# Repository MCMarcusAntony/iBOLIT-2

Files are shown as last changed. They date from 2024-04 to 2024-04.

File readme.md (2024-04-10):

--------------------------------------------------------------------------------
New iBolit Simple Diagnostics Cartridge version based on previous work done by
the RBSC group.
--------------------------------------------------------------------------------
- Last 16.07.2022 updates included.
- PCB design converted to KiCAD.
- All parts moved to throught hole to help to begginers build.
- Fuses for all voltages on the top slot.
- Connection to a right hand daughter board added.

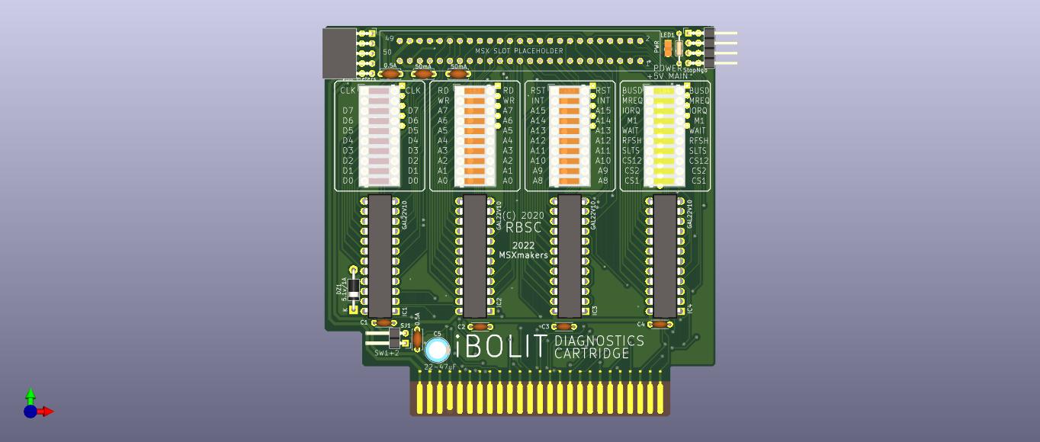
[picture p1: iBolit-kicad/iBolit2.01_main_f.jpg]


- Stop'n'go secondary daughter board design added.

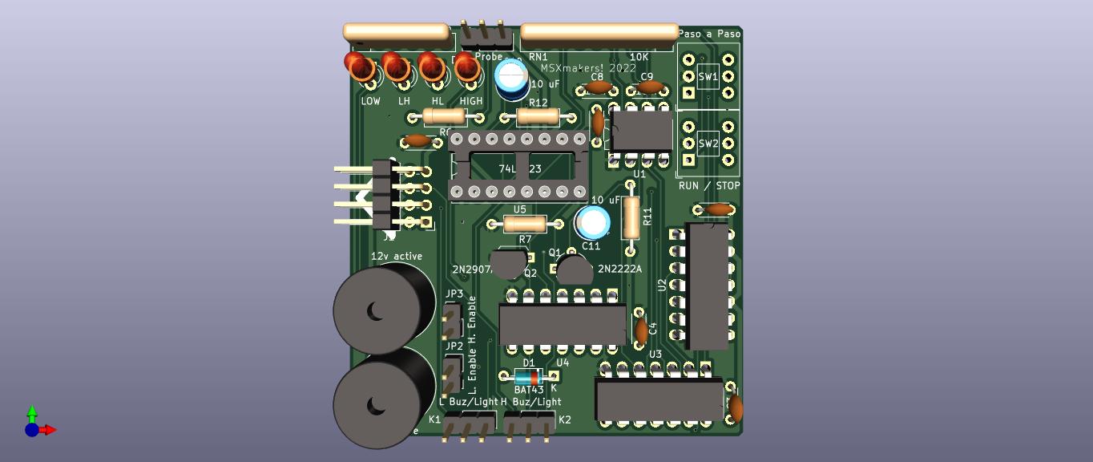
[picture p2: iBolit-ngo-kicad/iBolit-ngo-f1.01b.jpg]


Tools added to this board are:
- Logic probe included on Top three pin connector.
- Lighting and acoustic signals to identify HIGH and LOW status.

Code analisys tools (not properly working yet):
- Stop/Go switch the cpu to stop procesing opcodes.
- Step pushbutton to run just an opcode each time.

Development based on Steve Ciarcia design:
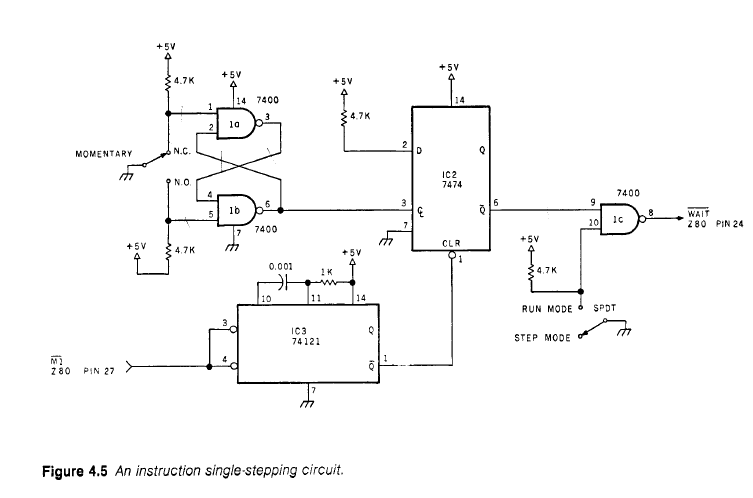
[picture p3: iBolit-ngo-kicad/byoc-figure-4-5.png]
byoc-figure-4-5


--------------------------------------------------------------------------------
iBolit Simple Diagnostics Cartridge
Copyright (c) 2020-2022 RBSC
Last updated: 16.07.2022
--------------------------------------------------------------------------------

UPDATE from 16.07.2022
----------------------

It's recommended to update the cartridge with an overvoltage protection. See the "iBolit_fuse.jpg" image in the Pics folder!

To install the overvoltage protection, isolate pin 24 of IC1 - cut the traces on both sides of the pin. Then purchase and
solder a 5.1V 1W rated zener diode between pins 12 and 24, the cathode should be connected to pin 24. Solder resettable fuse
0.5A between C2 and pin 24 of IC1. Solder a wire between C5 and the cut off trace to supply power to the voltmeters.

This way the PLD ICs and LEDs will be protected from the overvoltage while the 5V voltmeter will show exact voltage on the slot
connector.

About
-----

iBolit is a simple diagnostics cartridge. During the previous years we've seen numerous messages from MSX users, whose computers
suddenly stopped working after being removed from the storage or after another power cycle. Many people complained about black
screens or about total power failure. It's a known fact that RAM and other elements may go bad during storing or at power-on.
Diagnosing those problems usually starts from checking the power rails, clock signals, reset signal's state and activity on data
and address bus. It has been decided to create a simple diagnostics cartridge that could help to perform the initial check of a
computer and rule out the most common problems.

The cartridge that we named "iBolit" ( see Doctor Aybolit) was created using the GAL22V10 programmable logic chips, LED assemblies
and volt/ammeters from the PC's USB socket tester dongles. There's a cartridge slot installed on the top of iBolit cartridge's
board. There one can insert any cartridge including the one with MSX diagnostics ROM (there are a few, but it would be nice to
create a universal one). The GAL firmware is very primitive - if there's a high level on input, the LED connected to the output
will light up. The cartridge is fairly cheap to build - maximum 12-15 Euro - and is relatively easy to assemble. The daughterboard
with voltmeters is detachable.

Where to buy parts
------------------

The parts for assembling the cartridge can be purchased from these sellers on AliExpress:

 - https://www.aliexpress.com/item/32929139598.html   (buy the one with gray case and USB connectors on the left and right side)
 - https://www.aliexpress.com/item/4000078359420.html (buy 2 converters)
 - https://www.aliexpress.com/item/4001336380255.html (buy 2x5 pin headers)
 - https://www.aliexpress.com/item/32890057619.html   (buy 2x5 pin connectors)
 - https://www.aliexpress.com/item/4000970562846.html (also buy blue and yellow colors)
 - https://www.aliexpress.com/item/32800771545.html   (or use a different 5mm LED)
 - https://www.aliexpress.com/item/32918831775.html   (buy 1kOhm SMD resistor assemblies)
 - https://www.aliexpress.com/item/32948284513.html   (this LED is for the -12v voltmeter)
 - https://www.aliexpress.com/item/32375666910.html   (buy 10uF and 47uF capacitors)
 - https://www.aliexpress.com/item/4001146953252.html (buy 50-pin angled slot connector)

Assembling notes
----------------

Please read the following notes carefully:

 - It's highly recommended to install ceramic capacitors everywhere on the board. For the DC-DC converters the ceramic 10uF
   capacitors are a must

 - To adapt the voltmeters to work with iBolit, you need to first carefully open the USB tester's case with a knife and remove
   the board. Then desolder both indicator panels (mark one indicator panel to know where it came from) and desolder both USB
   connectors from the board. After that solder the indicator panels back to the board, but as low as possible. And finally
   solder two 4-pin pin headers to the board, the pins will have to be forces into the board because the distance between the
   holes is not 2.54mm

 - The voltmeter with a separate red LED is for -12v, it should be installed on the lowest position of the daughterboard. See
   the reference images

 - To install a small red LED to the -12v voltmeter (this step is optional), solder the cathode to the upper GND track and
   anode to the second pin from the top. See the reference images. The LED should be a bit above the voltmeter's board

 - Please note that LED assemblies may have incorrect key position! So please always test the LED assemblies with multimeter
   in the diode testing mode to find the correct polarity. The cathode should be on the right, like marked on the board

 - The pins of both DC-DC converters should be carefully bent at 90 degree angle and the converters have to be installed
   face-down. See the reference images

 - The GAL chips need to be programmed with the firmware before use. A widespread TL866 programmer will do just fine. Use
   the .JED firmware file from the "Firmware" folder and the "GAL22V10D" chip type when programming

 - Instead of one blue and two red LED assemblies you might want to install one red and two blue LED assemblies. Make your
   own choice. It's recommended to install the yellow LED assembly at the rightmost position. If you are installing the
   green LED assembly, you need to select a different value for the resistor assembly, for example 330 Ohm instead of 1kOhm

 - Before inserting the diagnostics board into the MSX slot it's highly recommend to make sure that +5v on the slot is within
   acceptable range (not more than 6-7v!), otherwise the diagnostics board may be damaged. The device doesn't have the
   over-voltage protection on the +5v rail

 - The daughterboard with voltmeters is detachable. When it is detached, no power will be supplied to the upper cartridge slot.
   If you need to use the cartridge slot without the attached daughterboard, you need to put 5 jumpers horizontally on 5 pairs
   of pins of the connector

IMPORTANT!
----------

The RBSC provides all the files and information for free, without any liability (see the disclaimer.txt file). The provided information,
software or hardware must not be used for commercial purposes unless permitted by the RBSC. Producing a small amount of bare boards for
personal projects and selling the rest of the batch is allowed without the permission of RBSC.

When the sources of the tools are used to create alternative projects, please always mention the original source and the copyright!

Contact information
-------------------

The members of RBSC group Tnt23, Wierzbowsky, Pencioner, Ptero, GreyWolf, SuperMax and DJS3000 can be contacted via the group's e-mail
address:

info@rbsc.su

The group's coordinator could be reached via this e-mail address:

admin@rbsc.su

The group's website can be found here:

https://rbsc.su/
https://rbsc.su/ru

The RBSC's hardware repository can be found here:

https://github.com/rbsc

The RBSC's 3D model repository can be found here:

https://www.thingiverse.com/groups/rbsc/things

-= ! MSX FOREVER ! =-

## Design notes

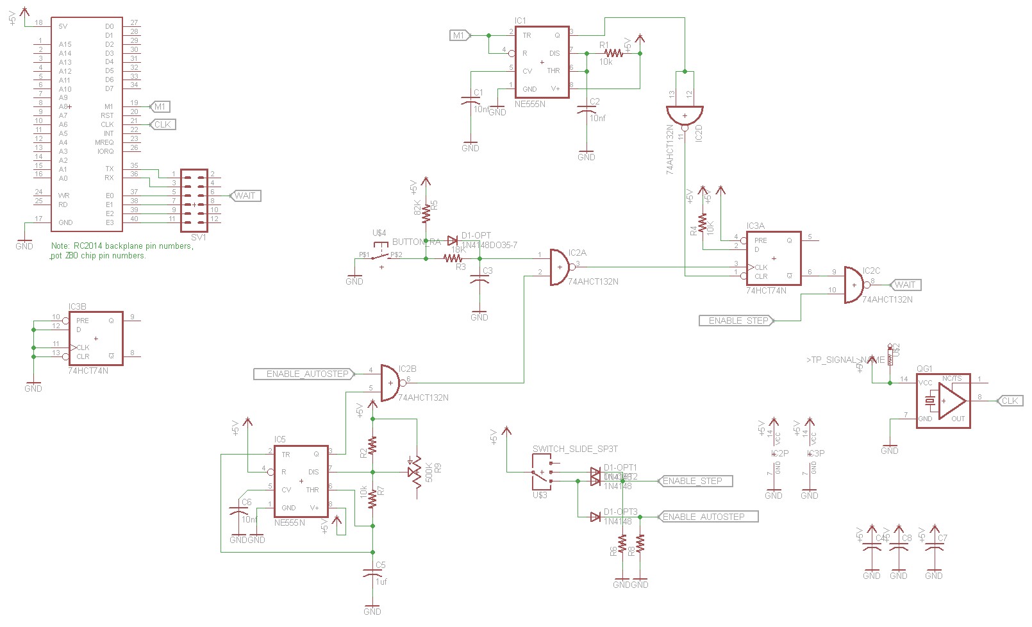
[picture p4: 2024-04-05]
iBolit-ngo-kicad/rc2014-singlestep-schematic1.jpg

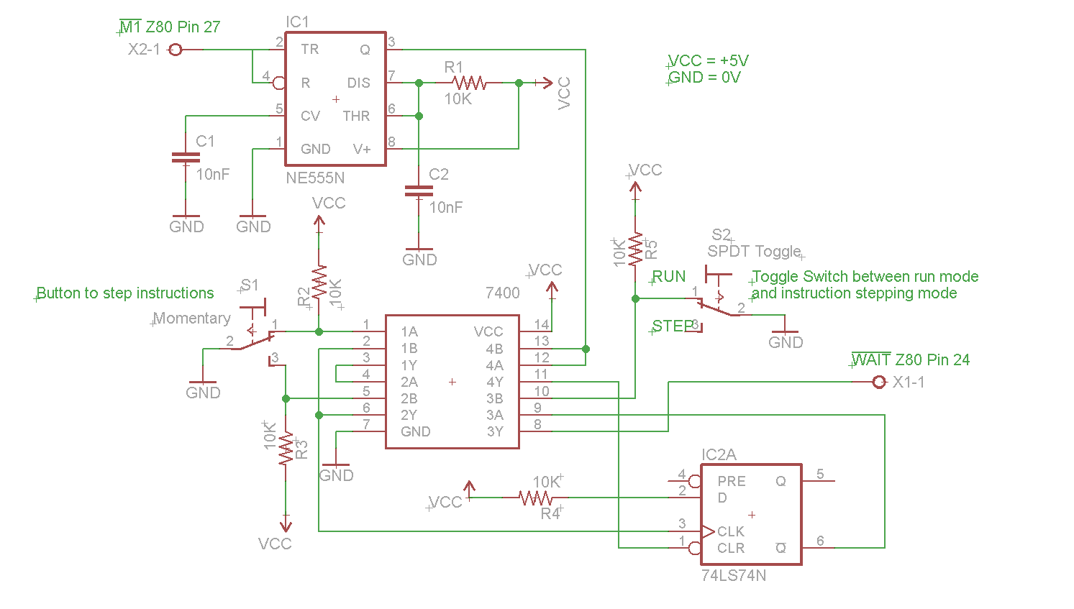
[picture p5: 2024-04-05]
iBolit-ngo-kicad/z80ssic-schematic1.png

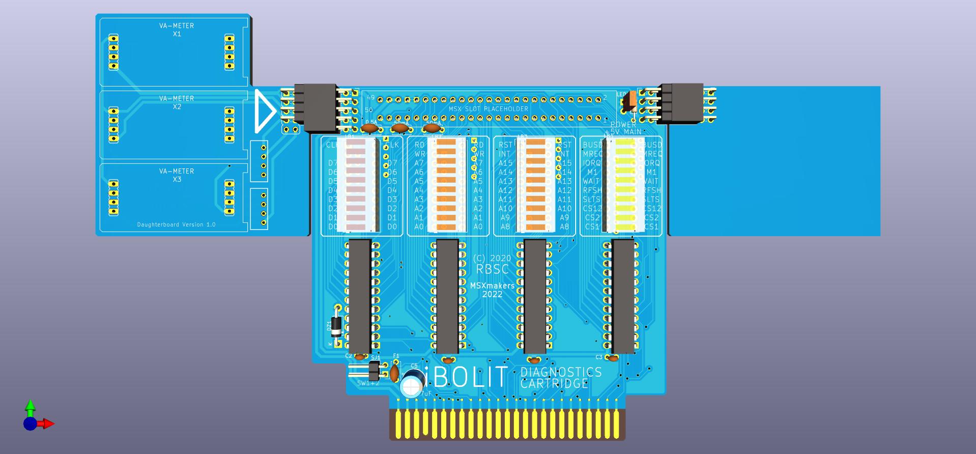
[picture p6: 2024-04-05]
iBolit-kicad/iBolit2.0_main_conjunto.jpg

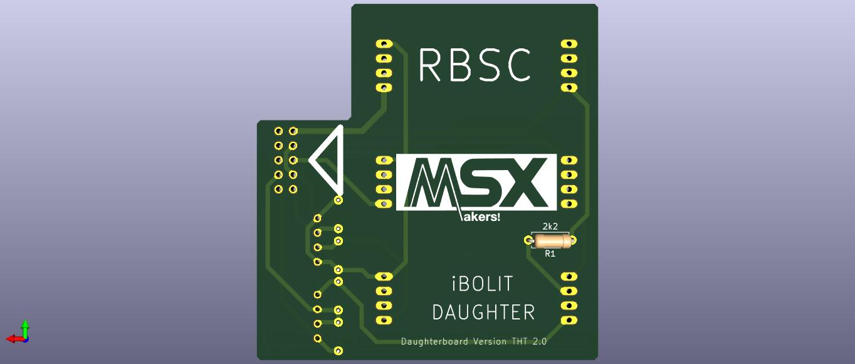
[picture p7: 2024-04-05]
iBolit-daughter-kicad/iBolit_daughter_v2_b.jpg

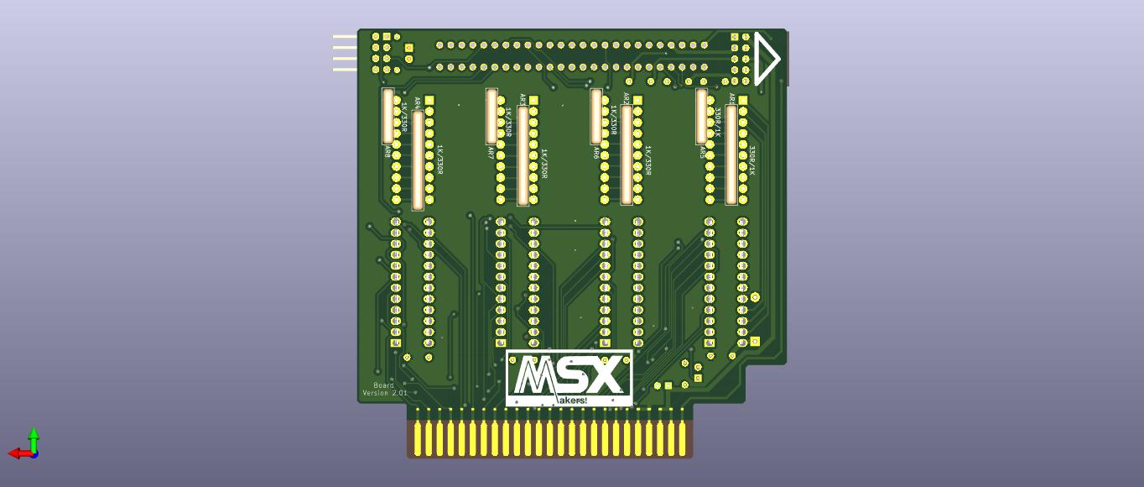
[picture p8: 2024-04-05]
iBolit-kicad/iBolit2.01_main_b.jpg

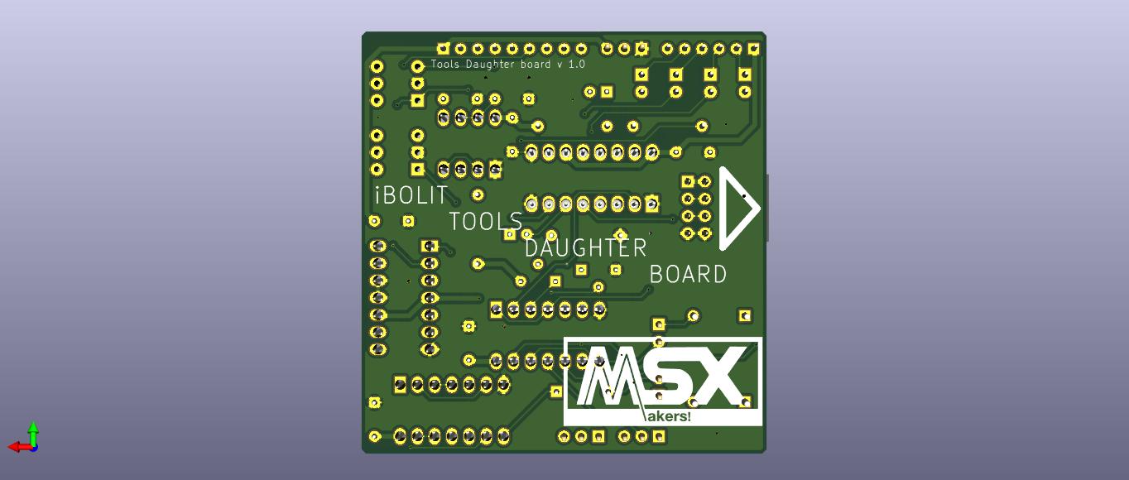
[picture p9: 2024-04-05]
iBolit-ngo-kicad/iBolit-ngo-b.jpg

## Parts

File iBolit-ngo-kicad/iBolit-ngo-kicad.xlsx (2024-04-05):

Reference | Quantity | Value | Footprint | Datasheet
C1 C2 C3 C4 C5 | 5 | 100nF | Capacitor_THT:C_Disc_D4.3mm_W1.9mm_P5.00mm
C10 C11 | 2 | 10 uF | Capacitor_THT:CP_Radial_D5.0mm_P2.50mm
C8 C9 | 2 | 10nF | Capacitor_THT:C_Disc_D4.3mm_W1.9mm_P5.00mm
D1 | 1 | BAT43 | Diode_THT:D_DO-35_SOD27_P7.62mm_Horizontal | http://www.vishay.com/docs/85660/bat42.pdf
D2 | 1 | HIGH | LED_THT:LED_D3.0mm
D3 | 1 | LOW | LED_THT:LED_D3.0mm
D4 | 1 | HL | LED_THT:LED_D3.0mm
D5 | 1 | LH | LED_THT:LED_D3.0mm
J1 | 1 | to MainBoard | Connector_PinSocket_2.54mm:PinSocket_2x04_P2.54mm_Horizontal
JP2 | 1 | L. Enable | Connector_PinHeader_2.54mm:PinHeader_1x02_P2.54mm_Vertical
JP3 | 1 | H. Enable | Connector_PinHeader_2.54mm:PinHeader_1x02_P2.54mm_Vertical
K1 | 1 | L Buz/Light | Connector_PinHeader_2.54mm:PinHeader_1x03_P2.54mm_Vertical
K2 | 1 | H Buz/Light | Connector_PinHeader_2.54mm:PinHeader_1x03_P2.54mm_Vertical
P1 | 1 | Probe | Connector_PinHeader_2.54mm:PinHeader_1x03_P2.54mm_Vertical
Q1 | 1 | 2N2222A | Package_TO_SOT_THT:TO-92L_Wide
Q2 | 1 | 2N2907A | Package_TO_SOT_THT:TO-92L_Wide
R11 R12 | 2 | 1K2 | Resistor_THT:R_Axial_DIN0207_L6.3mm_D2.5mm_P10.16mm_Horizontal
R6 R7 | 2 | 1K | Resistor_THT:R_Axial_DIN0207_L6.3mm_D2.5mm_P10.16mm_Horizontal
RN1 | 1 | 10K | Resistor_THT:R_Array_SIP9 | http://www.vishay.com/docs/31509/csc.pdf
RN2 | 1 | 180R | Resistor_THT:R_Array_SIP6 | http://www.vishay.com/docs/31509/csc.pdf
SP1 | 1 | 5v active | Buzzer_Beeper:MagneticBuzzer_ProSignal_ABI-009-RC
SP2 | 1 | 12v active | Buzzer_Beeper:MagneticBuzzer_ProSignal_ABI-009-RC
SW1 | 1 | Paso a Paso | Button_Switch_THT:SW_Push_2P2T_Toggle_CK_PVA2OAH5xxxxxxV2
SW2 | 1 | RUN / STOP | Button_Switch_THT:SW_Push_2P2T_Toggle_CK_PVA2OAH5xxxxxxV2
U1 | 1 | NE555N | MSXmakers:DIP-8c_W7.62mm_LongPads | http://www.ti.com/lit/ds/symlink/ne555.pdf
U2 | 1 | 74LS74 | MSXmakers:DIP-14c_W7.62mm_LongPads | 74xx/74hc_hct74.pdf
U3 | 1 | 74LS00 | MSXmakers:DIP-14c_W7.62mm_LongPads | http://www.ti.com/lit/gpn/sn74ls00
U4 | 1 | 74LS04 | MSXmakers:DIP-14c_W7.62mm_LongPads | http://www.ti.com/lit/gpn/sn74LS04
U5 | 1 | 74LS123 | MSXmakers:DIP-16c_W7.62mm_Socket_LongPads | http://www.ti.com/lit/gpn/sn74LS123

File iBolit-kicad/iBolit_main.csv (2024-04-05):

Reference | Quantity | Value | Footprint | Datasheet
AR1 AR2 AR3 AR4 | 4 | R_Network08 | Resistor_THT:R_Array_SIP9 | http://www.vishay.com/docs/31509/csc.pdf
AR5 AR6 AR7 AR8 | 4 | R_Network04 | Resistor_THT:R_Array_SIP5 | http://www.vishay.com/docs/31509/csc.pdf
C1 C2 C3 C4 | 4 | 100nF | Capacitor_THT:C_Disc_D3.0mm_W1.6mm_P2.50mm
C5 | 1 | 47uF/10v | Capacitor_THT:CP_Radial_D6.3mm_P2.50mm
CN1 | 1 | SLOTCONN | iBolit_main:MSX_SLOT_CON
CN2 | 1 | SLOTPLACEHOLDER | iBolit_main:MSX_SLOT_PLP
DZ1 | 1 | 5.1v/1A | Diode_THT:D_DO-41_SOD81_P10.16mm_Horizontal
F1 F2 | 2 | 0.5A | Capacitor_THT:C_Disc_D5.0mm_W2.5mm_P5.00mm
F3 F4 | 2 | 50mA | Capacitor_THT:C_Disc_D5.0mm_W2.5mm_P5.00mm
IC1 IC2 IC3 IC4 | 4 | GAL22V10 | MSXmakers:DIP-24c_W7.62mm_LongPads
J2 | 1 | StopNgo | Connector_PinHeader_2.54mm:PinHeader_2x04_P2.54mm_Horizontal
JP1 | 1 | JP5Q_CUSTOM | Connector_PinSocket_2.54mm:PinSocket_2x05_P2.54mm_Horizontal
LB1 | 1 | LEDBLOCK10 | Display:HDSP-4832
LB2 LB3 | 2 | LEDBLOCK10 | Display:HDSP-4830
LB4 | 1 | LEDBLOCK10 | Display:HDSP-4850
LED1 | 1 | LED5MM | LED_THT:LED_Rectangular_W3.9mm_H1.8mm
R2 | 1 | 1k | Resistor_THT:R_Axial_DIN0204_L3.6mm_D1.6mm_P7.62mm_Horizontal
SJ1 | 1 | SJ | Connector_PinHeader_2.54mm:PinHeader_1x02_P2.54mm_Horizontal

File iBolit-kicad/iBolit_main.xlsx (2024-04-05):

Reference | Value | Footprint | Datasheet
IC1 | GAL22V10 | iBolit_main:DIL24-3
IC2 | GAL22V10 | iBolit_main:DIL24-3
IC3 | GAL22V10 | iBolit_main:DIL24-3
IC4 | GAL22V10 | iBolit_main:DIL24-3
C1 | 100nF | iBolit_main:C0805
C5 | 47uF 10v | iBolit_main:SMC_B
CN2 | SLOTPLACEHOLDER | iBolit_main:MSX_SLOT_PLP
C2 | 100nF | iBolit_main:C0805
C3 | 100nF | iBolit_main:C0805
C4 | 100nF | iBolit_main:C0805
LB1 | LEDBLOCK10 | iBolit_main:LB10
LB2 | LEDBLOCK10 | iBolit_main:LB10
LB3 | LEDBLOCK10 | iBolit_main:LB10
LB4 | LEDBLOCK10 | iBolit_main:LB10
CN1 | SLOTCONN | iBolit_main:MSX_SLOT_CON
RN1 | CTS742C083 | iBolit_main:CTS742C083
RN2 | CTS742C083 | iBolit_main:CTS742C083
RN3 | CTS742C083 | iBolit_main:CTS742C083
RN4 | CTS742C083 | iBolit_main:CTS742C083
RN5 | CTS742C083 | iBolit_main:CTS742C083
RN6 | CTS742C083 | iBolit_main:CTS742C083
RN7 | CTS742C083 | iBolit_main:CTS742C083
RN8 | CTS742C083 | iBolit_main:CTS742C083
RN9 | CTS742C083 | iBolit_main:CTS742C083
RN10 | CTS742C083 | iBolit_main:CTS742C083
RN11 | CTS742C083 | iBolit_main:CTS742C083
RN12 | CTS742C083 | iBolit_main:CTS742C083
JP1 | JP5Q_CUSTOM | iBolit_main:JP5Q_CUSTOM
R2 | 1k | iBolit_main:R0805
LED1 | LED5MM | iBolit_main:LED5MM
SJ1 | SJ | iBolit_main:SJ

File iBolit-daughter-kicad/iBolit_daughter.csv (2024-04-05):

Reference | Value | Footprint | Datasheet
R1 | 2k2 | iBolit_daughter:R0805
X1 | VA-METER | iBolit_daughter:VA_METER
X2 | VA-METER | iBolit_daughter:VA_METER
X3 | VA-METER | iBolit_daughter:VA_METER
DC1 | VA-?S | iBolit_daughter:4SIL
DC2 | VA-?S | iBolit_daughter:4SIL
JP2 | JP5Q_CUSTOM | iBolit_daughter:JP5Q_CUSTOM
JP3 | JP4E_CUSTOM | iBolit_daughter:JP4_CUSTOM
JP4 | JP4E_CUSTOM | iBolit_daughter:JP4_CUSTOM
JP5 | JP4E_CUSTOM | iBolit_daughter:JP4_CUSTOM
JP6 | JP4E_CUSTOM | iBolit_daughter:JP4_CUSTOM
JP7 | JP4E_CUSTOM | iBolit_daughter:JP4_CUSTOM
JP8 | JP4E_CUSTOM | iBolit_daughter:JP4_CUSTOM
C6 | 10-47uF | iBolit_daughter:C1210
C7 | 10-47uF | iBolit_daughter:C1210
C8 | 10-47uF | iBolit_daughter:C1210
C9 | 10-47uF | iBolit_daughter:C1210

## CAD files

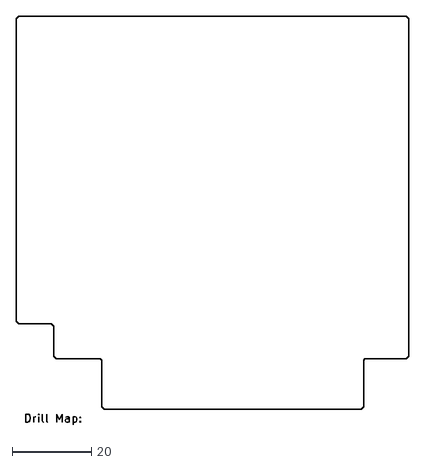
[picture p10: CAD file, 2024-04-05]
iBolit-kicad/iBolit_main-NPTH-drl_map.dxf
99.1 x 103.0

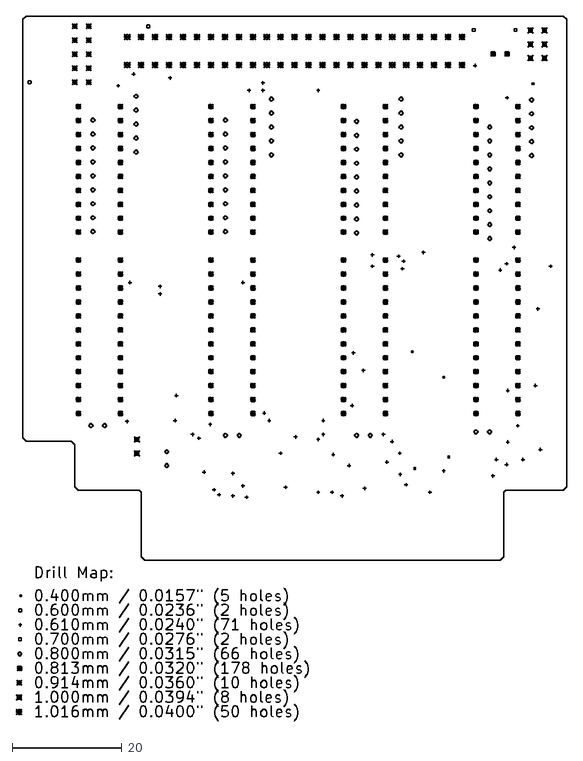
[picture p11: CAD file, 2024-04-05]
iBolit-kicad/iBolit_main-PTH-drl_map.dxf
100.2 x 128.4

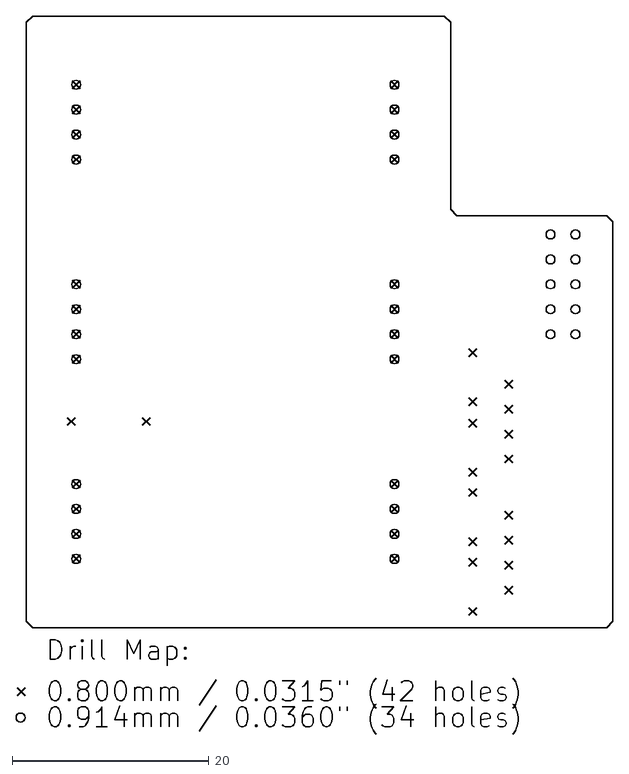
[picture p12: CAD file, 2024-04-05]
iBolit-daughter-kicad/gerber_v2.0/iBolit_daughter-PTH-drl_map.dxf
60.7 x 73.1

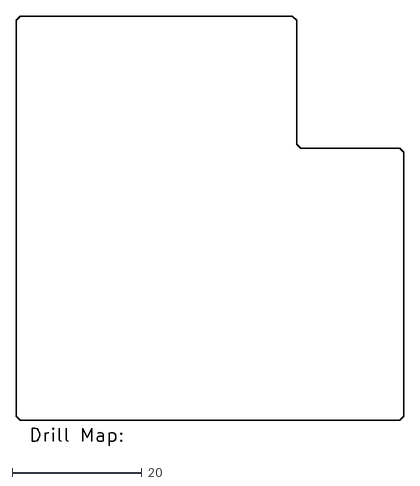
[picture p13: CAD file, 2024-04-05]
iBolit-daughter-kicad/gerber_v2.0/iBolit_daughter-NPTH-drl_map.dxf
59.7 x 66.1

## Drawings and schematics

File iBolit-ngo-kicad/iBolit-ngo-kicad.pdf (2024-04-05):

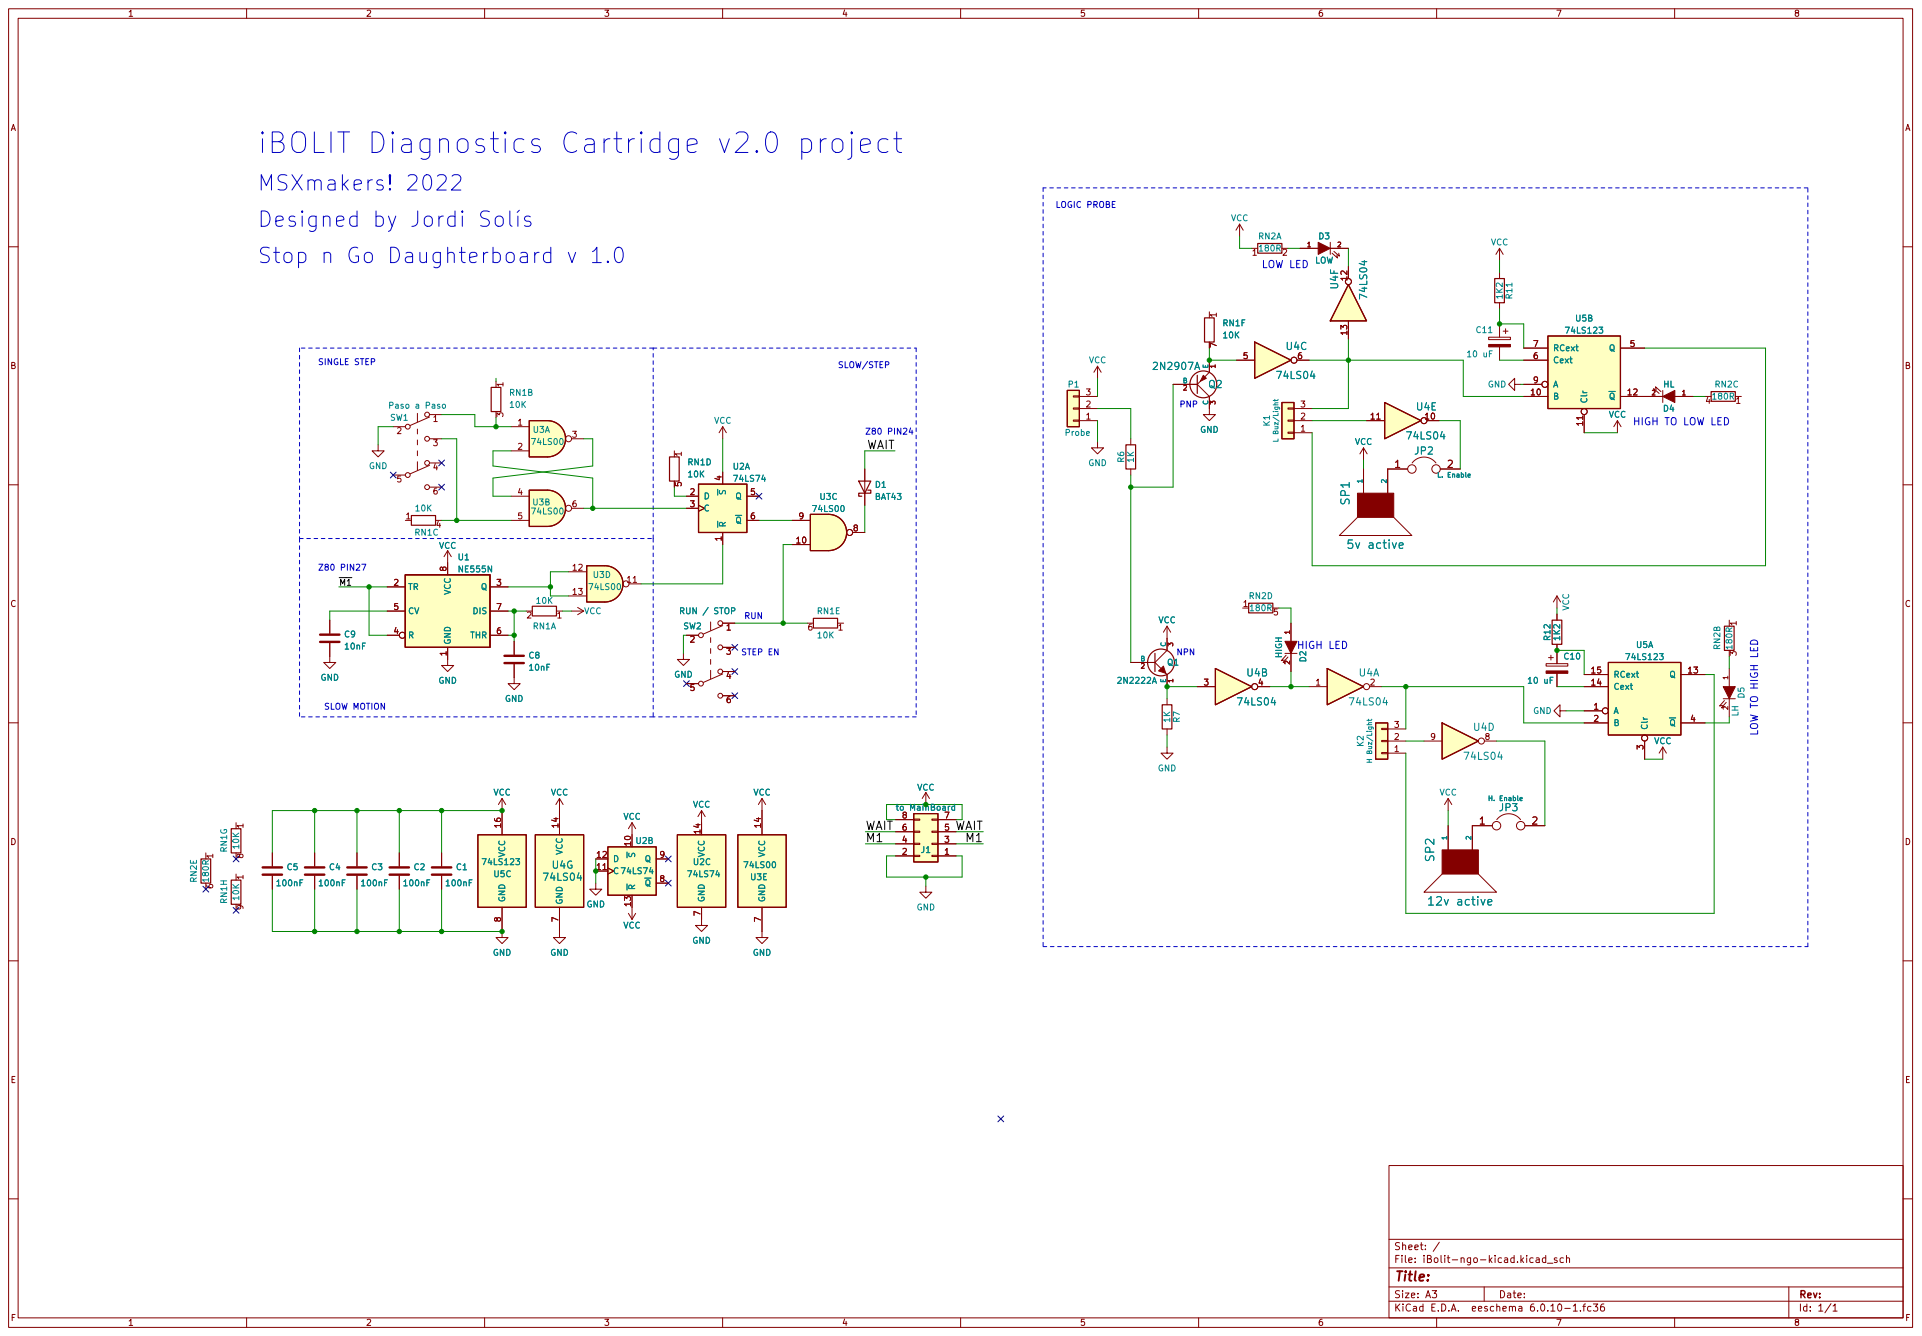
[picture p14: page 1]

PNP iBOLIT Diagnostics Cartridge v2.0 project

HIGH TO LOW LED

File: iBolit-ngo-kicad.kicad_sch Sheet: /

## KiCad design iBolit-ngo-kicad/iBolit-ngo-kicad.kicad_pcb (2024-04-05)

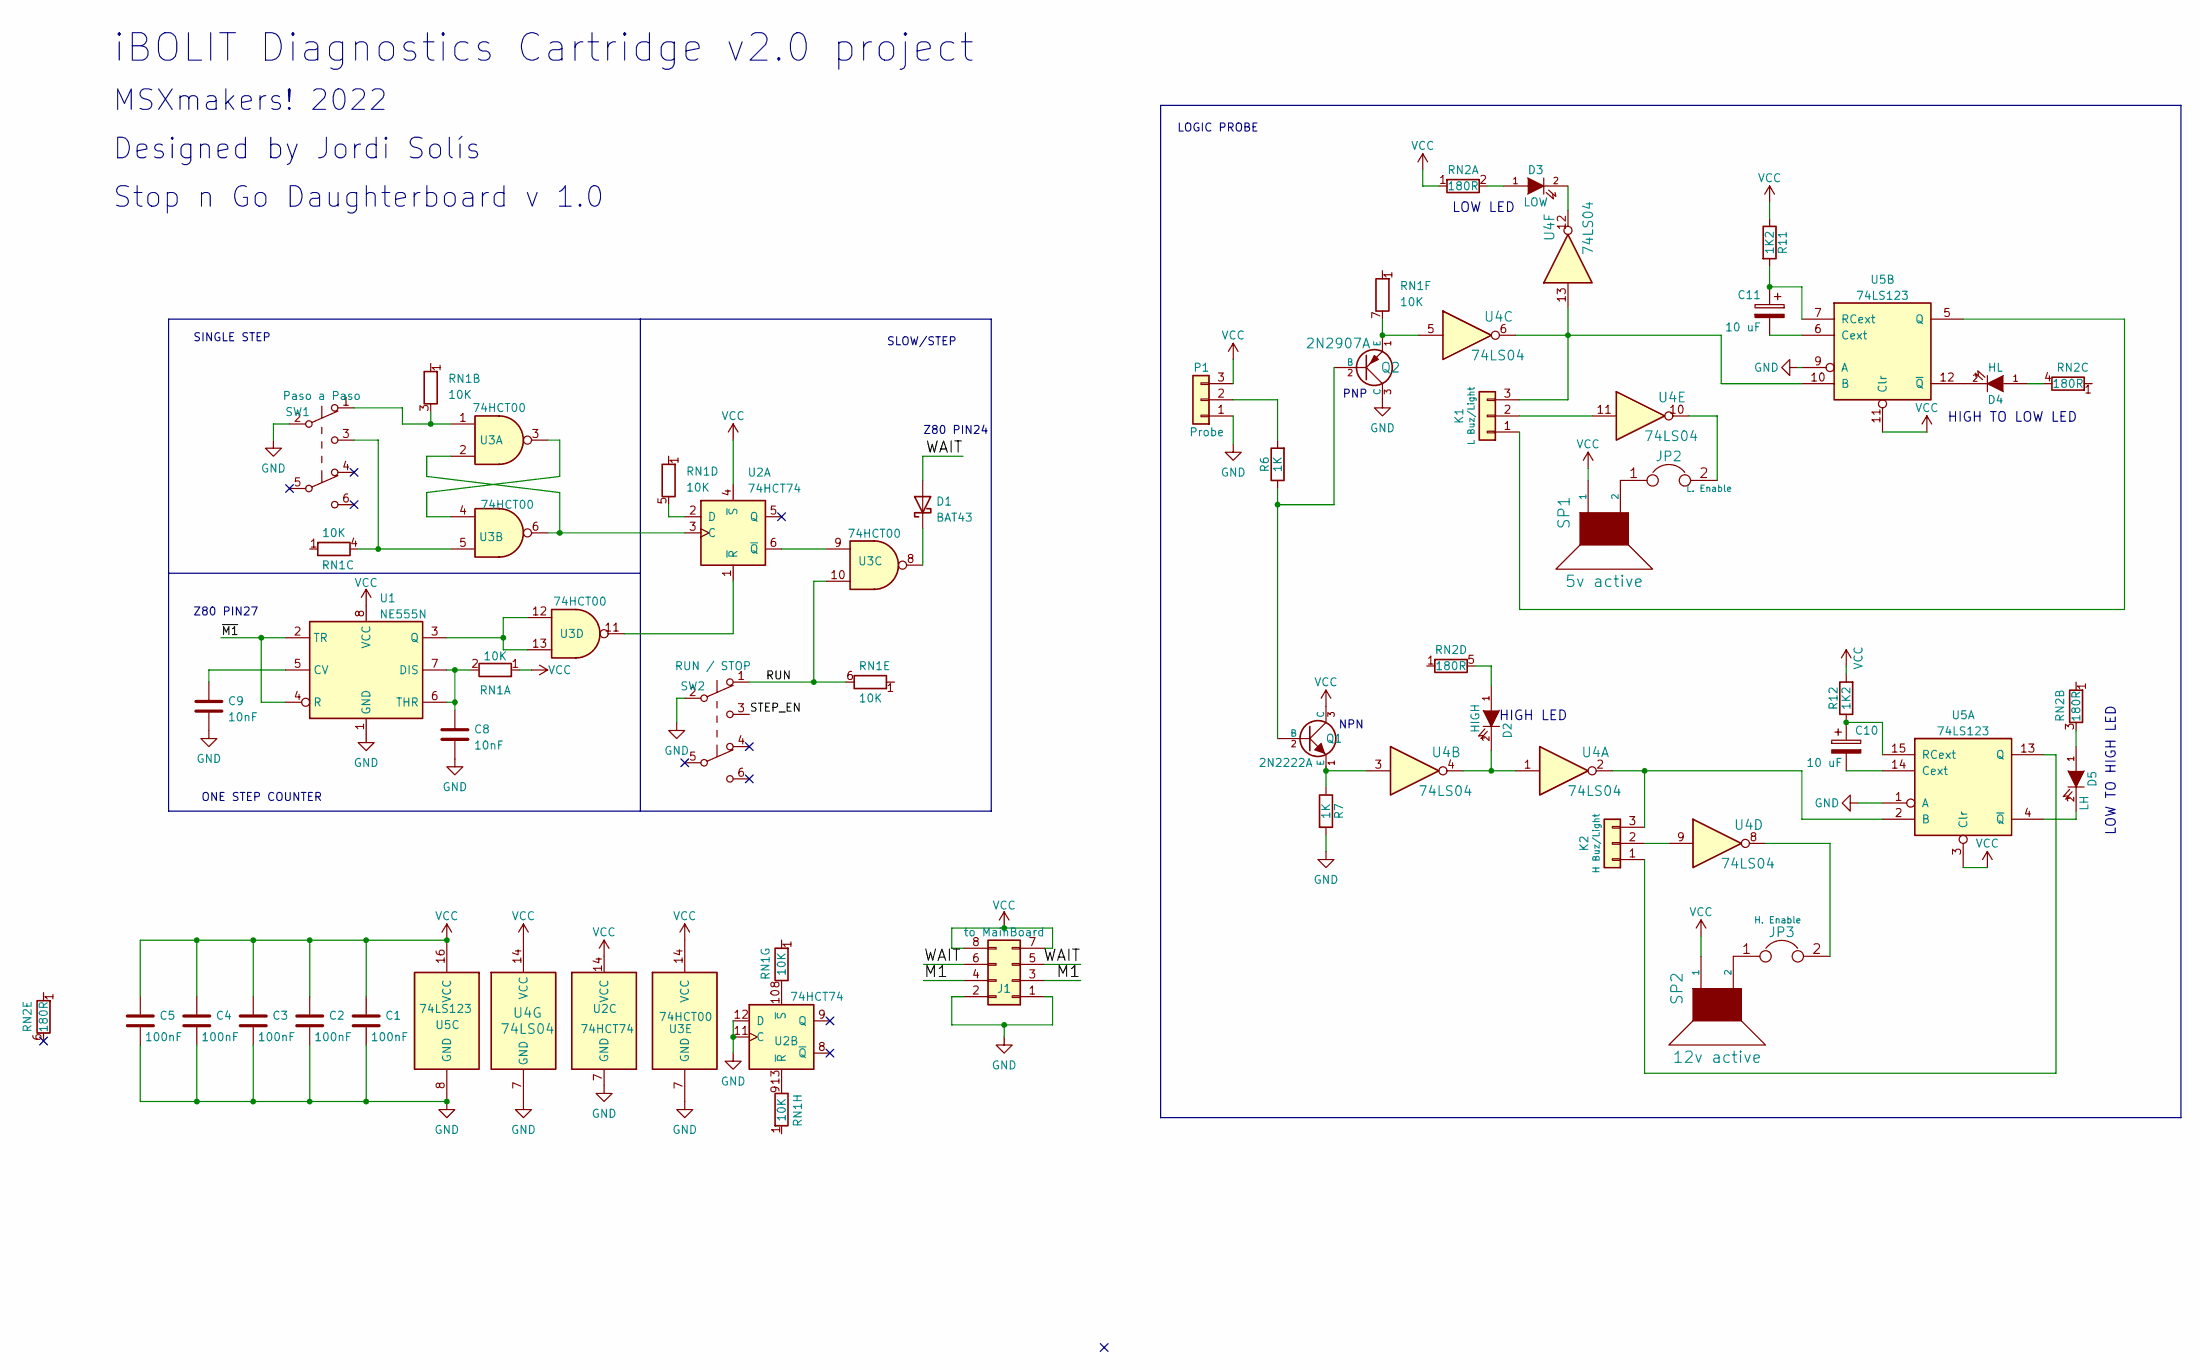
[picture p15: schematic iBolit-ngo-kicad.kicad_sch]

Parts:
C1, C2, C3, C4, C5: 100nF; C_Disc_D4.3mm_W1.9mm_P5.00mm
C8, C9: 10nF; C_Disc_D4.3mm_W1.9mm_P5.00mm
C10, C11: 10 uF; CP_Radial_D5.0mm_P2.50mm
D1: BAT43; D_DO-35_SOD27_P7.62mm_Horizontal
D2: HIGH; LED_D3.0mm
D3: LOW; LED_D3.0mm
D4: HL; LED_D3.0mm
D5: LH; LED_D3.0mm
J1: to MainBoard; PinHeader_2x04_P2.54mm_Horizontal
JP2: L. Enable; PinHeader_1x02_P2.54mm_Vertical
JP3: H. Enable; PinHeader_1x02_P2.54mm_Vertical
K1: L Buz/Light; PinHeader_1x03_P2.54mm_Vertical
K2: H Buz/Light; PinHeader_1x03_P2.54mm_Vertical
P1: Probe; PinHeader_1x03_P2.54mm_Vertical
Q1: 2N2222A; TO-92L_Wide
Q2: 2N2907A; TO-92L_Wide
R6, R7: 1K; R_Axial_DIN0207_L6.3mm_D2.5mm_P10.16mm_Horizontal
R11, R12: 1K2; R_Axial_DIN0207_L6.3mm_D2.5mm_P10.16mm_Horizontal
RN1: 10K; R_Array_SIP9
RN2: 180R; R_Array_SIP6
SP1: 5v active; MagneticBuzzer_ProSignal_ABI-009-RC
SP2: 12v active; MagneticBuzzer_ProSignal_ABI-009-RC
SW1: Paso a Paso; SW_Push_2P2T_Toggle_CK_PVA2OAH5xxxxxxV2
SW2: RUN / STOP; SW_Push_2P2T_Toggle_CK_PVA2OAH5xxxxxxV2
U1: NE555N; DIP-8c_W7.62mm_LongPads
U2: 74HCT74; DIP-14c_W7.62mm_LongPads
U3: 74HCT00; DIP-14c_W7.62mm_LongPads
U4: 74LS04; DIP-14c_W7.62mm_LongPads
U5: 74LS123; DIP-16c_W7.62mm_Socket_LongPads

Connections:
/M1: J1.3, J1.4
/RUN: RN1.6 (R5.2), SW1.4 (A), SW2.1 (A), U3.10
/STEP_EN: SW1.5 (B), SW2.3 (C)
/WAIT: D1.2 (A), J1.5, J1.6
/~M1: U1.2 (TR), U1.4 (R)
GND: C1.2, C2.2, C3.2, C4.2, C5.2, C8.2, C9.2, J1.1, J1.2, P1.1, Q2.3 (C), R7.2, SW1.2 (B), SW2.2 (B), U1.1 (GND), U2.7 (GND), U2.11 (C), U2.12 (D), U3.7 (GND), U4.7 (GND), U5.1 (A), U5.8 (GND), U5.9 (A)
unnamed: D1.1 (K), U3.8
unnamed: D2.1 (A), RN2.5 (R4.2)
unnamed: D2.2 (K), U4.1, U4.4
unnamed: D3.1 (A), RN2.2 (R1.2)
unnamed: D3.2 (K), U4.12
unnamed: D4.1 (A), RN2.4 (R3.2)
unnamed: D4.2 (K), U5.12 (~Q)
unnamed: D5.1 (A), RN2.3 (R2.2)
unnamed: D5.2 (K), U5.4 (~Q)
unnamed: JP2.1, SP1.2
unnamed: JP2.2, U4.10
unnamed: JP3.1, SP2.2
unnamed: JP3.2, U4.8
unnamed: K1.1, U5.5 (Q)
unnamed: K1.2, U4.11
unnamed: K1.3, U4.6, U4.13, U5.10 (B)
unnamed: K2.1, U5.13 (Q)
unnamed: K2.2, U4.9
unnamed: K2.3, U4.2, U5.2 (B)
unnamed: P1.2, R6.2
unnamed: Q1.2 (B), Q2.2 (B), R6.1
unnamed: Q1.1 (E), R7.1, U4.3
unnamed: Q2.1 (E), RN1.7 (R6.2), U4.5
unnamed: C8.1, RN1.2 (R1.2), U1.6 (THR), U1.7 (DIS)
unnamed: RN1.3 (R2.2), SW1.1 (A), U3.1
unnamed: RN1.4 (R3.2), SW1.3 (C), U3.5
unnamed: RN1.5 (R4.2), U2.2 (D)
unnamed: C9.1, U1.5 (CV)
unnamed: U1.3 (Q), U3.12, U3.13
unnamed: U2.3 (C), U3.2, U3.6
unnamed: U2.6 (~Q), U3.9
unnamed: U2.1 (~R), U3.11
unnamed: U3.3, U3.4
unnamed: C10.2, U5.14 (Cext)
unnamed: C10.1, R12.1, U5.15 (RCext)
unnamed: C11.2, U5.6 (Cext)
unnamed: C11.1, R11.2, U5.7 (RCext)

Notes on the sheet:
LOGIC PROBE
Stop n Go Daughterboard v 1.0
Designed by Jordi Solís
MSXmakers! 2022
ONE STEP COUNTER
HIGH TO LOW LED
LOW TO HIGH LED
iBOLIT Diagnostics Cartridge v2.0 project
HIGH LED
NPN
Z80 PIN24
SINGLE STEP
LOW LED
PNP
SLOW/STEP
Z80 PIN27

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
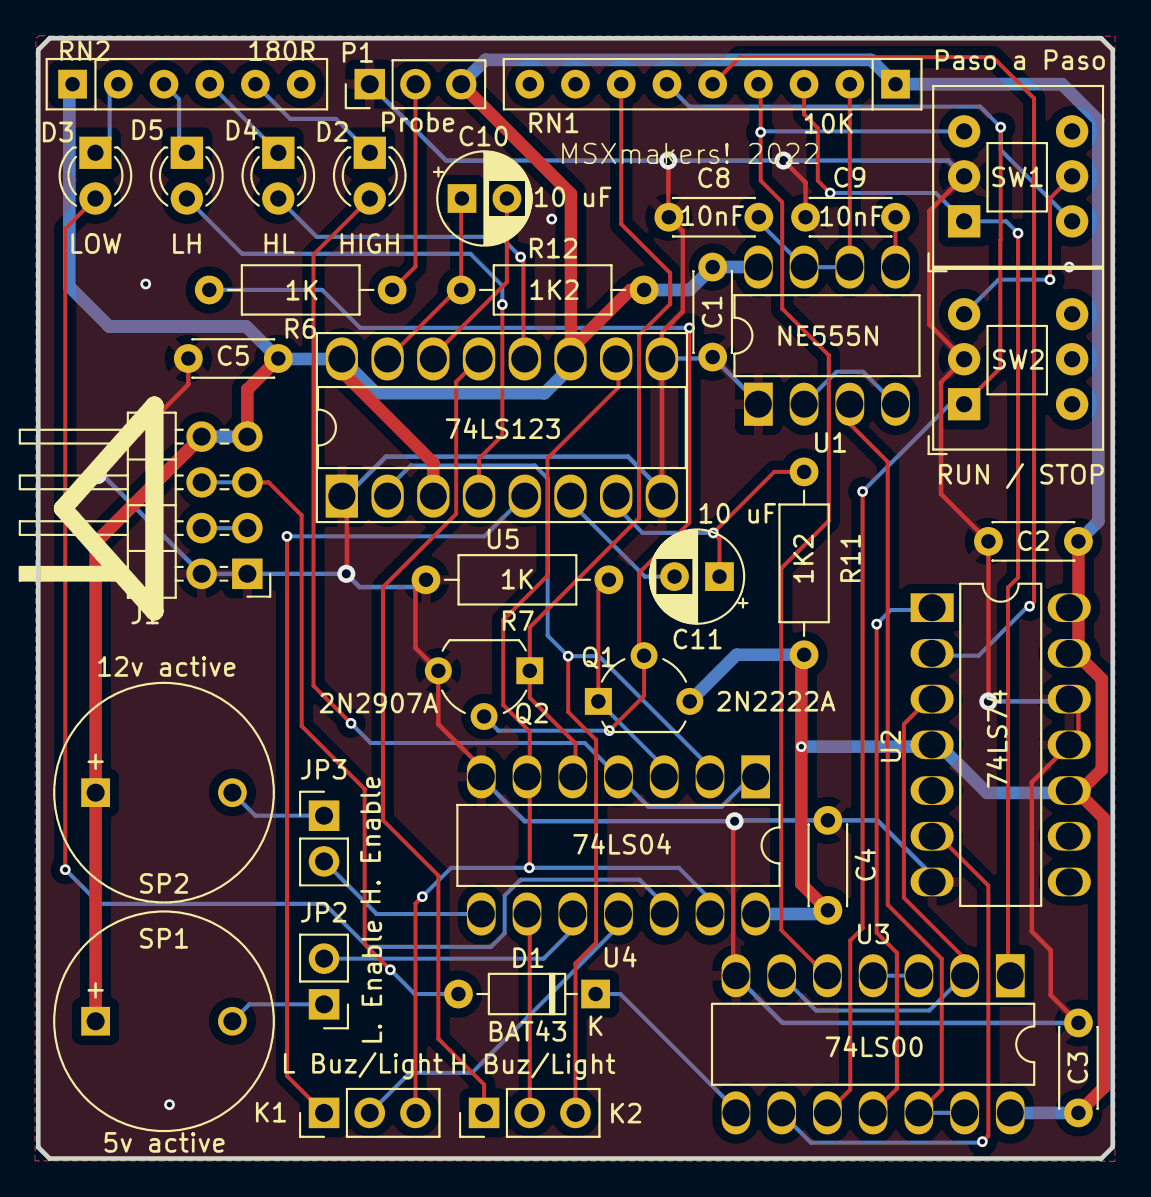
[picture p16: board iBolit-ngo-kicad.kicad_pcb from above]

Board: 2 copper layers, 59.7 x 62.2 mm, 37 parts (0 on the bottom side), 44 nets.

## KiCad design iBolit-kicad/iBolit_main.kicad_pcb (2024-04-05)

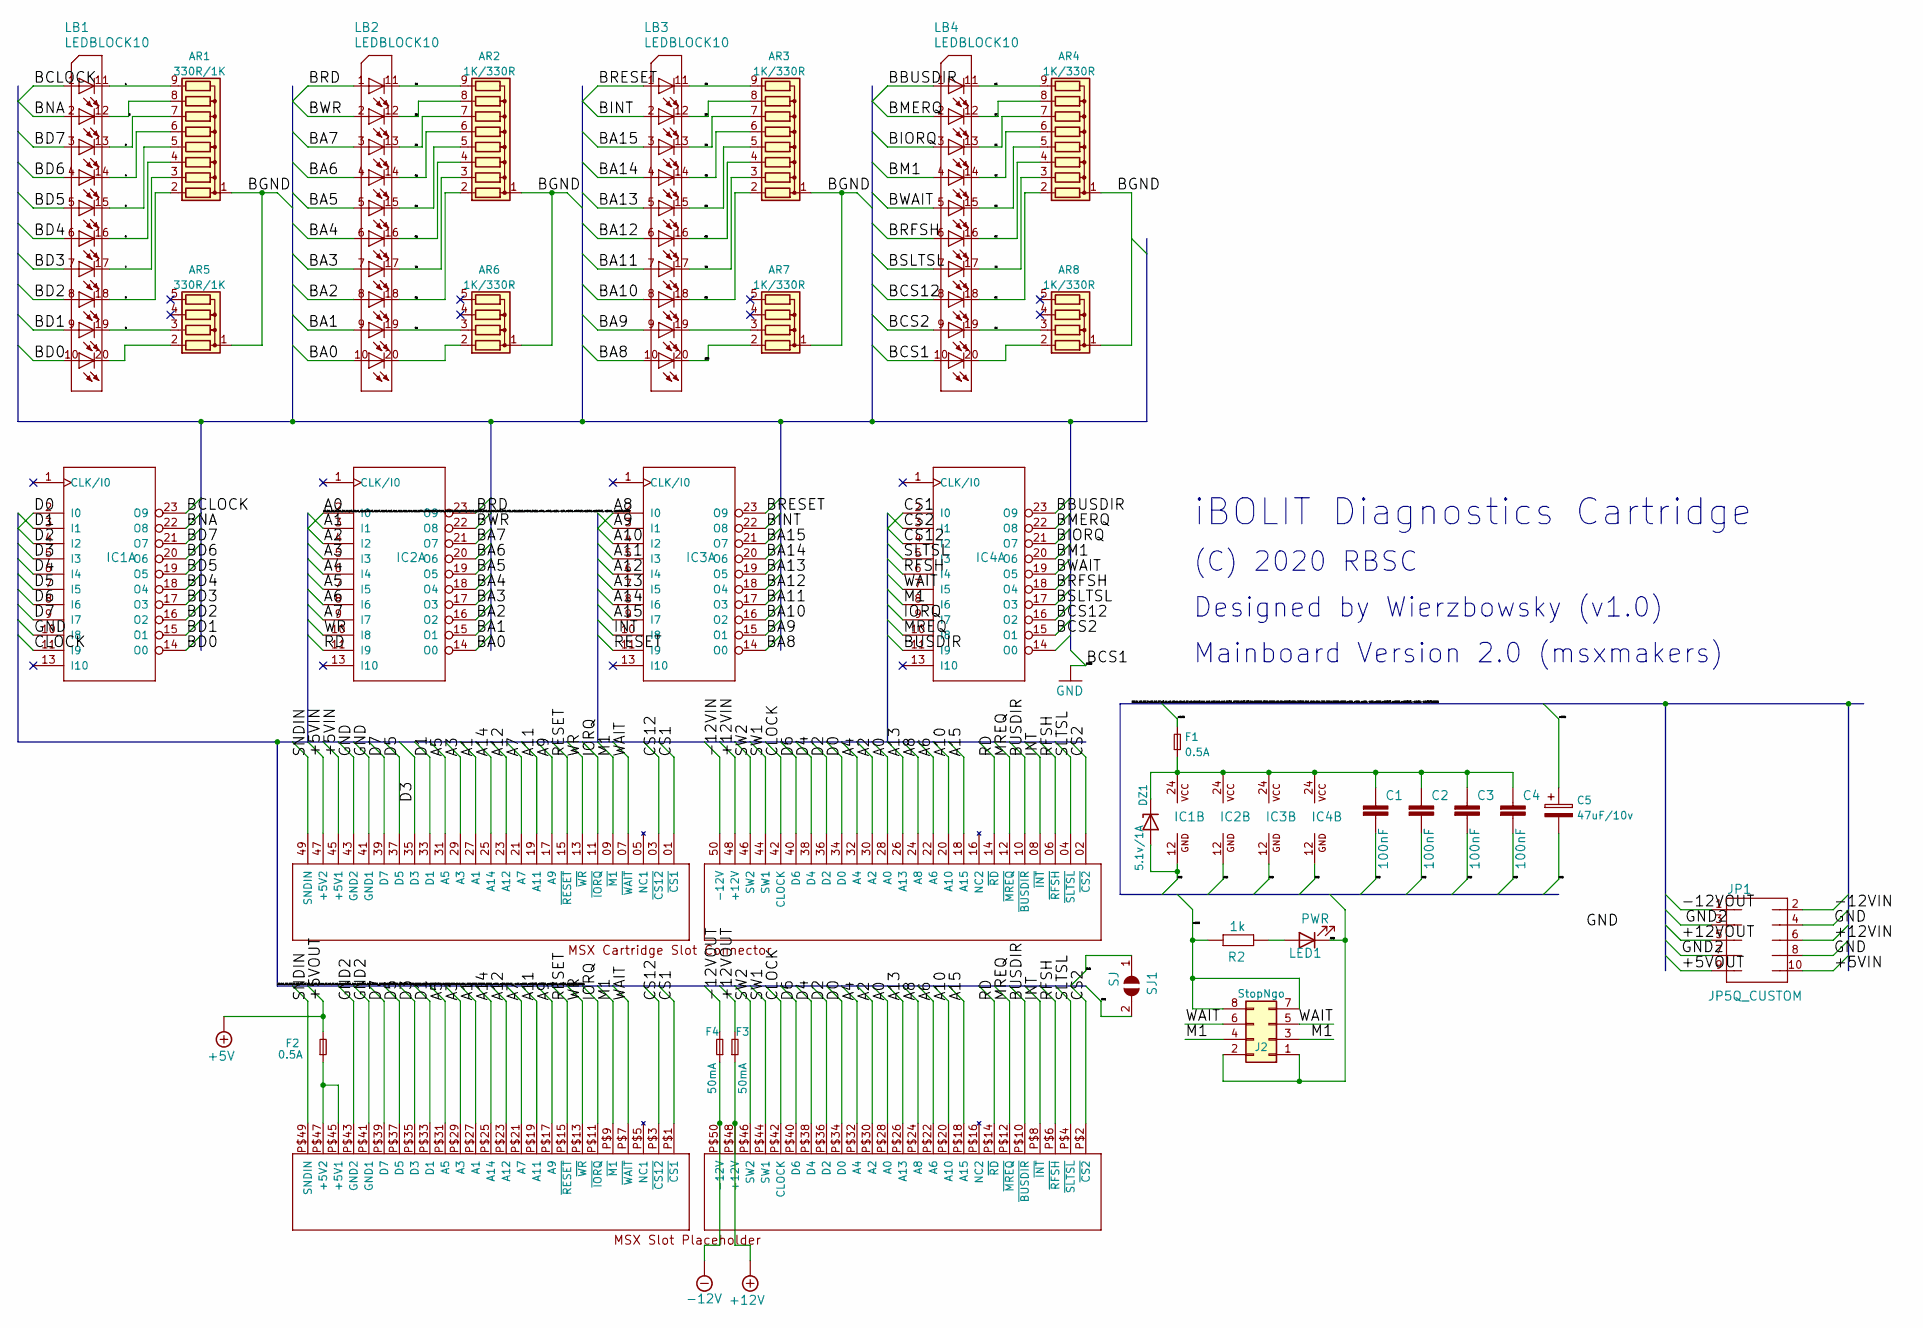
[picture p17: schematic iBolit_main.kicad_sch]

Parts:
AR1: 330R/1K; R_Array_SIP9
AR2, AR3, AR4: 1K/330R; R_Array_SIP9
AR5: 330R/1K; R_Array_SIP5
AR6, AR7, AR8: 1K/330R; R_Array_SIP5
C1, C2, C3, C4: 100nF; C_Disc_D4.3mm_W1.9mm_P5.00mm
C5: 47uF/10v; CP_Radial_D6.3mm_P2.50mm
CN1: SLOTCONN; MSX_SLOT_CON
CN2: SLOTPLACEHOLDER; MSX_SLOT_PLP
DZ1: 5.1v/1A; D_DO-41_SOD81_P10.16mm_Horizontal
F1, F2: 0.5A; C_Disc_D5.0mm_W2.5mm_P5.00mm
F3, F4: 50mA; C_Disc_D5.0mm_W2.5mm_P5.00mm
IC1, IC2, IC3, IC4: GAL22V10; DIP-24c_W7.62mm_LongPads
J2: StopNgo; PinSocket_2x04_P2.54mm_Horizontal
JP1: JP5Q_CUSTOM; PinHeader_2x05_P2.54mm_Horizontal
LB1: LEDBLOCK10; HDSP-4832
LB2, LB3: LEDBLOCK10; HDSP-4830
LB4: LEDBLOCK10; HDSP-4850
LED1: PWR; LED_Rectangular_W3.9mm_H1.8mm
R2: 1k; R_Axial_DIN0204_L3.6mm_D1.6mm_P7.62mm_Horizontal
SJ1: SJ; PinHeader_1x02_P2.54mm_Horizontal

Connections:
+5V: F2.2, JP1.9
+12V: CN2.P$48 (+12V), F3.1
-12V: CN2.P$50 (-12V), F4.1
/1: AR1.9 (R8), LB1.11 (L1O)
/1A: AR2.9 (R8), LB2.11 (L1O)
/1B: AR3.9 (R8), LB3.11 (L1O)
/1C: AR4.9 (R8), LB4.11 (L1O)
/2: AR1.8 (R7), LB1.12 (L1O1)
/2A: AR2.8 (R7), LB2.12 (L1O1)
/2B: AR3.8 (R7), LB3.12 (L1O1)
/2C: AR4.8 (R7), LB4.12 (L1O1)
/3: AR1.7 (R6), LB1.13 (L1O2)
/3A: AR2.7 (R6), LB2.13 (L1O2)
/3B: AR3.7 (R6), LB3.13 (L1O2)
/3C: AR4.7 (R6), LB4.13 (L1O2)
/4: AR1.6 (R5), LB1.14 (L1O3)
/4A: AR2.6 (R5), LB2.14 (L1O3)
/4B: AR3.6 (R5), LB3.14 (L1O3)
/4C: AR4.6 (R5), LB4.14 (L1O3)
/5: AR1.5 (R4), LB1.15 (L1O4)
/5A: AR2.5 (R4), LB2.15 (L1O4)
/5B: AR3.5 (R4), LB3.15 (L1O4)
/5C: AR4.5 (R4), LB4.15 (L1O4)
/6: AR1.4 (R3), LB1.16 (L1O5)
/6A: AR2.4 (R3), LB2.16 (L1O5)
/6B: AR3.4 (R3), LB3.16 (L1O5)
/6C: AR4.4 (R3), LB4.16 (L1O5)
/7: AR1.3 (R2), LB1.17 (L1O6)
/7A: AR2.3 (R2), LB2.17 (L1O6)
/7B: AR3.3 (R2), LB3.17 (L1O6)
/7C: AR4.3 (R2), LB4.17 (L1O6)
/8: AR1.2 (R1), LB1.18 (L1O7)
/8A: AR2.2 (R1), LB2.18 (L1O7)
/8B: AR3.2 (R1), LB3.18 (L1O7)
/8C: AR4.2 (R1), LB4.18 (L1O7)
/9: AR5.3 (R2), LB1.19 (L1O8)
/9A: AR6.3 (R2), LB2.19 (L1O8)
/9C: AR8.3 (R2), LB4.19 (L1O8)
/10B: AR7.2 (R1), LB3.20 (L1O9)
/+5VIN: C5.1, CN1.45 (+5V1), CN1.47 (+5V2), F1.2, J2.7, J2.8, JP1.10, R2.2
/+12VIN: CN1.48 (+12V), JP1.6
/+12VOUT: F3.2, JP1.5
/-12VIN: CN1.50 (-12V), JP1.2
/-12VOUT: F4.2, JP1.1
/A0: CN1.28 (A0), CN2.P$28 (A0), IC2.2 (I0)
/A1: CN1.27 (A1), CN2.P$27 (A1), IC2.3 (I1)
/A2: CN1.30 (A2), CN2.P$30 (A2), IC2.4 (I2)
/A3: CN1.29 (A3), CN2.P$29 (A3), IC2.5 (I3)
/A4: CN1.32 (A4), CN2.P$32 (A4), IC2.6 (I4)
/A5: CN1.31 (A5), CN2.P$31 (A5), IC2.7 (I5)
/A6: CN1.22 (A6), CN2.P$22 (A6), IC2.8 (I6)
/A7: CN1.21 (A7), CN2.P$21 (A7), IC2.9 (I7)
/A8: CN1.24 (A8), CN2.P$24 (A8), IC3.2 (I0)
/A9: CN1.17 (A9), CN2.P$17 (A9), IC3.3 (I1)
/A10: CN1.20 (A10), CN2.P$20 (A10), IC3.4 (I2)
/A11: CN1.19 (A11), CN2.P$19 (A11), IC3.5 (I3)
/A12: CN1.23 (A12), CN2.P$23 (A12), IC3.6 (I4)
/A13: CN1.26 (A13), CN2.P$26 (A13), IC3.7 (I5)
/A14: CN1.25 (A14), CN2.P$25 (A14), IC3.8 (I6)
/A15: CN1.18 (A15), CN2.P$18 (A15), IC3.9 (I7)
/BA0: IC2.14 (O0), LB2.10 (L1I9)
/BA1: IC2.15 (O1), LB2.9 (L1I8)
/BA2: IC2.16 (O2), LB2.8 (L1I7)
/BA3: IC2.17 (O3), LB2.7 (L1I6)
/BA4: IC2.18 (O4), LB2.6 (L1I5)
/BA5: IC2.19 (O5), LB2.5 (L1I4)
/BA6: IC2.20 (O6), LB2.4 (L1I3)
/BA7: IC2.21 (O7), LB2.3 (L1I2)
/BA8: IC3.14 (O0), LB3.10 (L1I9)
/BA9: IC3.15 (O1), LB3.9 (L1I8)
/BA10: IC3.16 (O2), LB3.8 (L1I7)
/BA11: IC3.17 (O3), LB3.7 (L1I6)
/BA12: IC3.18 (O4), LB3.6 (L1I5)
/BA13: IC3.19 (O5), LB3.5 (L1I4)
/BA14: IC3.20 (O6), LB3.4 (L1I3)
/BA15: IC3.21 (O7), LB3.3 (L1I2)
/BBUSDIR: IC4.23 (O9), LB4.1 (L1I)
/BCLOCK: IC1.23 (O9), LB1.1 (L1I)
/BCS2: IC4.15 (O1), LB4.9 (L1I8)
/BCS12: IC4.16 (O2), LB4.8 (L1I7)
/BD0: IC1.14 (O0), LB1.10 (L1I9)
/BD1: IC1.15 (O1), LB1.9 (L1I8)
/BD2: IC1.16 (O2), LB1.8 (L1I7)
/BD3: IC1.17 (O3), LB1.7 (L1I6)
/BD4: IC1.18 (O4), LB1.6 (L1I5)
/BD5: IC1.19 (O5), LB1.5 (L1I4)
/BD6: IC1.20 (O6), LB1.4 (L1I3)
/BD7: IC1.21 (O7), LB1.3 (L1I2)
/BINT: IC3.22 (O8), LB3.2 (L1I1)
/BIORQ: IC4.21 (O7), LB4.3 (L1I2)
/BM1: IC4.20 (O6), LB4.4 (L1I3)
/BMERQ: IC4.22 (O8), LB4.2 (L1I1)
/BNA: IC1.22 (O8), LB1.2 (L1I1)
/BRD: IC2.23 (O9), LB2.1 (L1I)
/BRESET: IC3.23 (O9), LB3.1 (L1I)
/BRFSH: IC4.18 (O4), LB4.6 (L1I5)
/BSLTSL: IC4.17 (O3), LB4.7 (L1I6)
/BUSDIR: CN1.10 (~BUSDIR), CN2.P$10 (~BUSDIR), IC4.11 (I9)
/BWAIT: IC4.19 (O5), LB4.5 (L1I4)
/BWR: IC2.22 (O8), LB2.2 (L1I1)
/CLOCK: CN1.42 (CLOCK), CN2.P$42 (CLOCK), IC1.11 (I9)
/CS1: CN1.01 (~CS1), CN2.P$1 (~CS1), IC4.2 (I0)
/CS2: CN1.02 (~CS2), CN2.P$2 (~CS2), IC4.3 (I1)
/CS12: CN1.03 (~CS12), CN2.P$3 (~CS12), IC4.4 (I2)
/D0: CN1.34 (D0), CN2.P$34 (D0), IC1.2 (I0)
/D1: CN1.33 (D1), CN2.P$33 (D1), IC1.3 (I1)
/D2: CN1.36 (D2), CN2.P$36 (D2), IC1.4 (I2)
/D3: CN1.35 (D3), CN2.P$35 (D3), IC1.5 (I3)
/D4: CN1.38 (D4), CN2.P$38 (D4), IC1.6 (I4)
/D5: CN1.37 (D5), CN2.P$37 (D5), IC1.7 (I5)
/D6: CN1.40 (D6), CN2.P$40 (D6), IC1.8 (I6)
/D7: CN1.39 (D7), CN2.P$39 (D7), IC1.9 (I7)
/GND2: CN2.P$41 (GND1), CN2.P$43 (GND2), JP1.3, JP1.7
/INT: CN1.08 (~INT), CN2.P$8 (~INT), IC3.10 (I8)
/IORQ: CN1.11 (~IORQ), CN2.P$11 (~IORQ), IC4.9 (I7)
/M1: CN1.09 (~M1), CN2.P$9 (~M1), IC4.8 (I6), J2.3, J2.4
/MREQ: CN1.12 (~MREQ), CN2.P$12 (~MREQ), IC4.10 (I8)
/RD: CN1.14 (~RD), CN2.P$14 (~RD), IC2.11 (I9)
/RESET: CN1.15 (~RESET), CN2.P$15 (~RESET), IC3.11 (I9)
/RFSH: CN1.06 (~RFSH), CN2.P$6 (~RFSH), IC4.6 (I4)
/SLTSL: CN1.04 (~SLTSL), CN2.P$4 (~SLTSL), IC4.5 (I3)
/SNDIN: CN1.49 (SNDIN), CN2.P$49 (SNDIN)
/SW1: CN1.44 (SW1), CN2.P$44 (SW1), SJ1.2
/SW2: CN1.46 (SW2), CN2.P$46 (SW2), SJ1.1
/WAIT: CN1.07 (~WAIT), CN2.P$7 (~WAIT), IC4.7 (I5), J2.5, J2.6
/WR: CN1.13 (~WR), CN2.P$13 (~WR), IC2.10 (I8)
GND: AR1.1 (common), AR2.1 (common), AR3.1 (common), AR4.1 (common), AR5.1 (common), AR6.1 (common), AR7.1 (common), AR8.1 (common), C1.2, C2.2, C3.2, C4.2, C5.2, CN1.41 (GND1), CN1.43 (GND2), DZ1.2 (A), IC1.10 (I8), IC1.12 (GND), IC2.12 (GND), IC3.12 (GND), IC4.12 (GND), J2.1, J2.2, JP1.4, JP1.8, LB4.10 (L1I9), LED1.1 (K)
unnamed: AR5.2 (R1), LB1.20 (L1O9)
unnamed: AR6.2 (R1), LB2.20 (L1O9)
unnamed: AR7.3 (R2), LB3.19 (L1O8)
unnamed: AR8.2 (R1), LB4.20 (L1O9)
unnamed: C1.1, C2.1, C3.1, C4.1, DZ1.1 (K), F1.1, IC1.24 (VCC), IC2.24 (VCC), IC3.24 (VCC), IC4.24 (VCC)
unnamed: CN2.P$45 (+5V1), CN2.P$47 (+5V2), F2.1
unnamed: LED1.2 (A), R2.1

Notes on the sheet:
(C) 2020 RBSC
Mainboard Version 2.0 (msxmakers)
Designed by Wierzbowsky (v1.0)
iBOLIT Diagnostics Cartridge

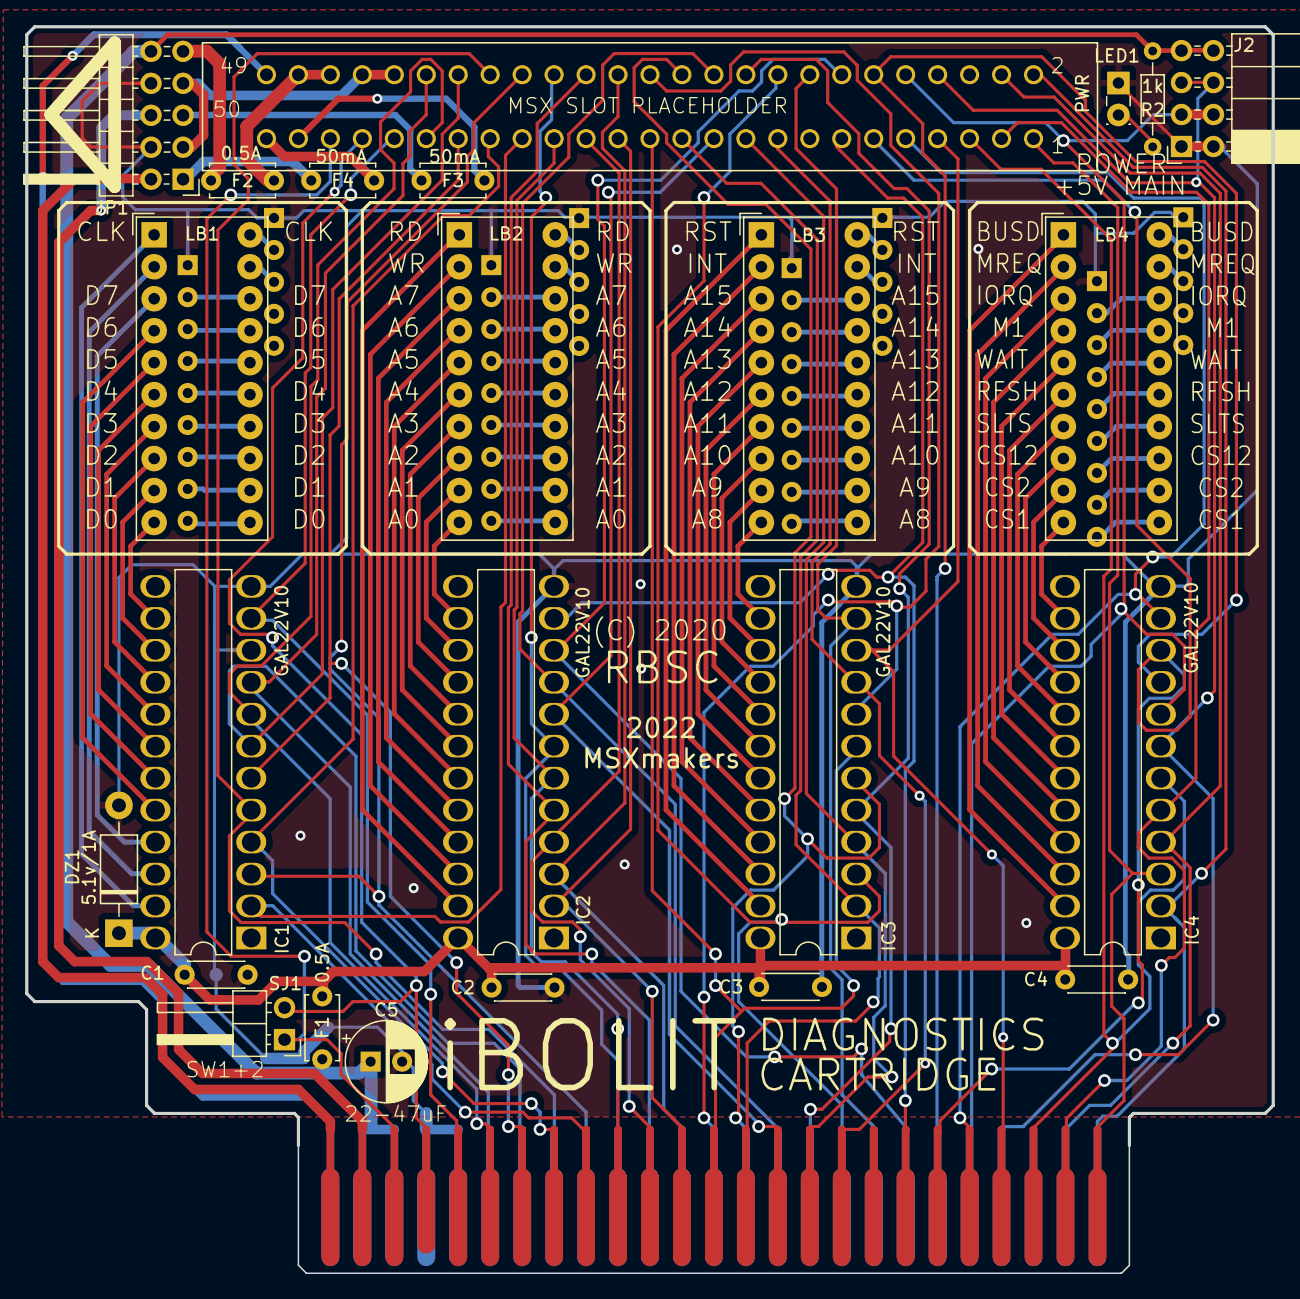
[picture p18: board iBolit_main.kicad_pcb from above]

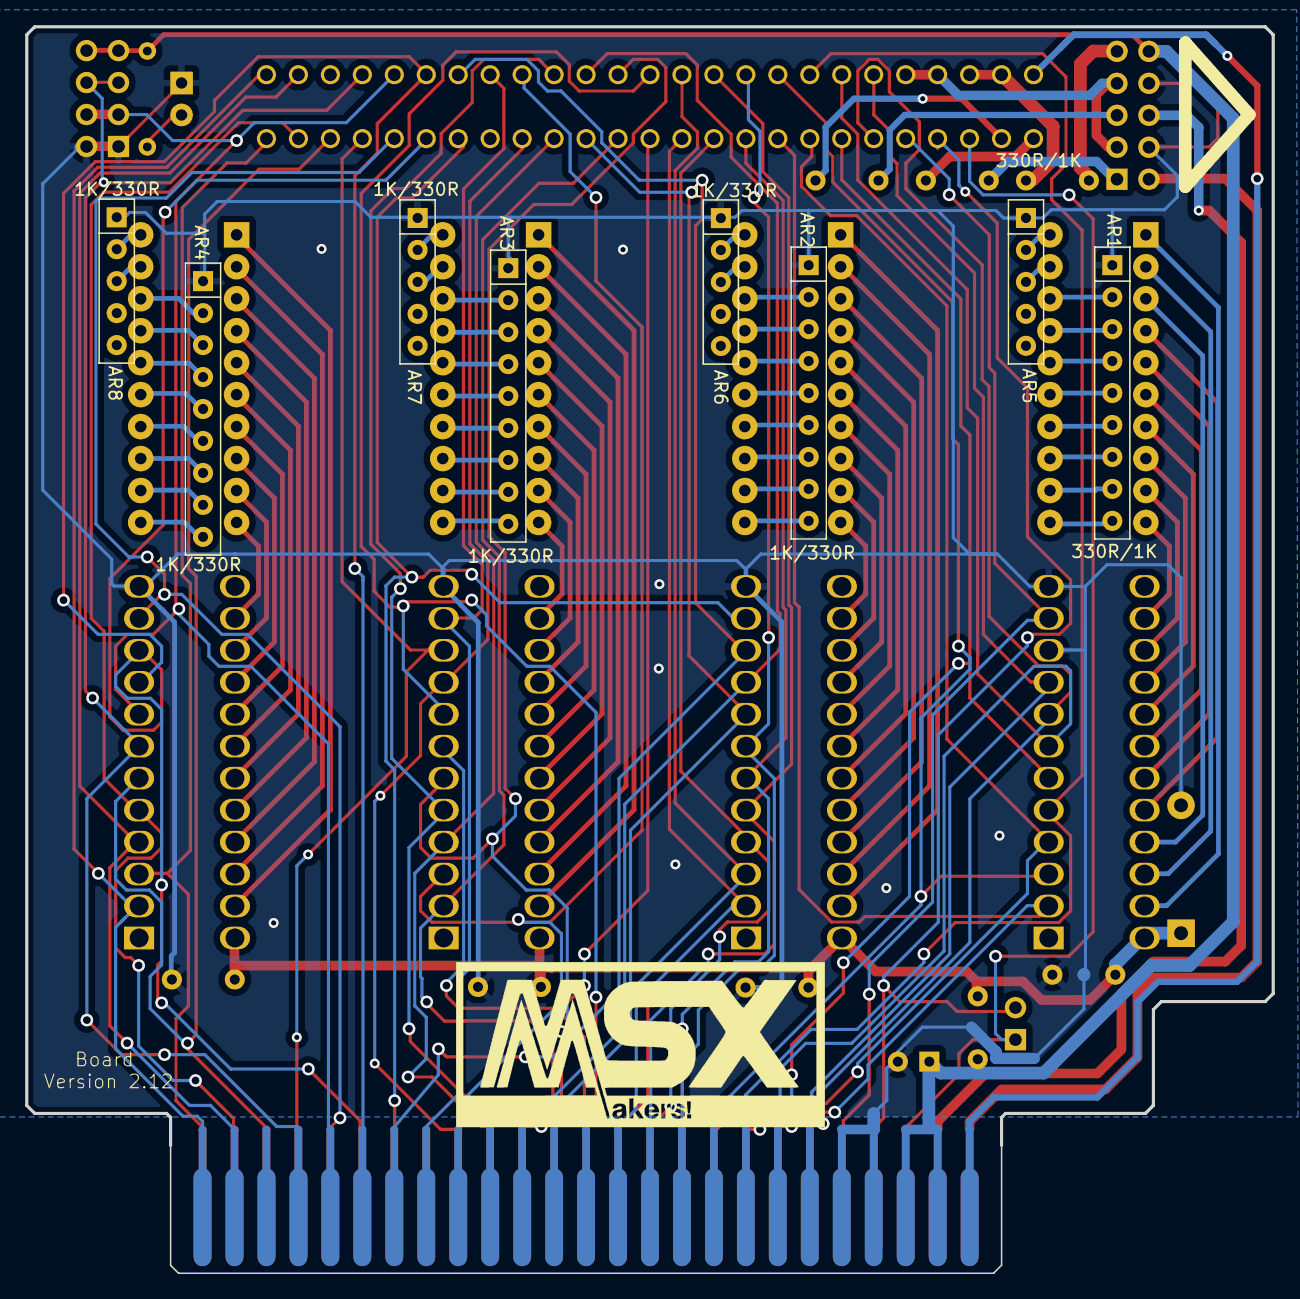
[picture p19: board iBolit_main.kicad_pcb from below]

Board: 2 copper layers, 99.1 x 99.1 mm, 33 parts (8 on the bottom side), 134 nets.

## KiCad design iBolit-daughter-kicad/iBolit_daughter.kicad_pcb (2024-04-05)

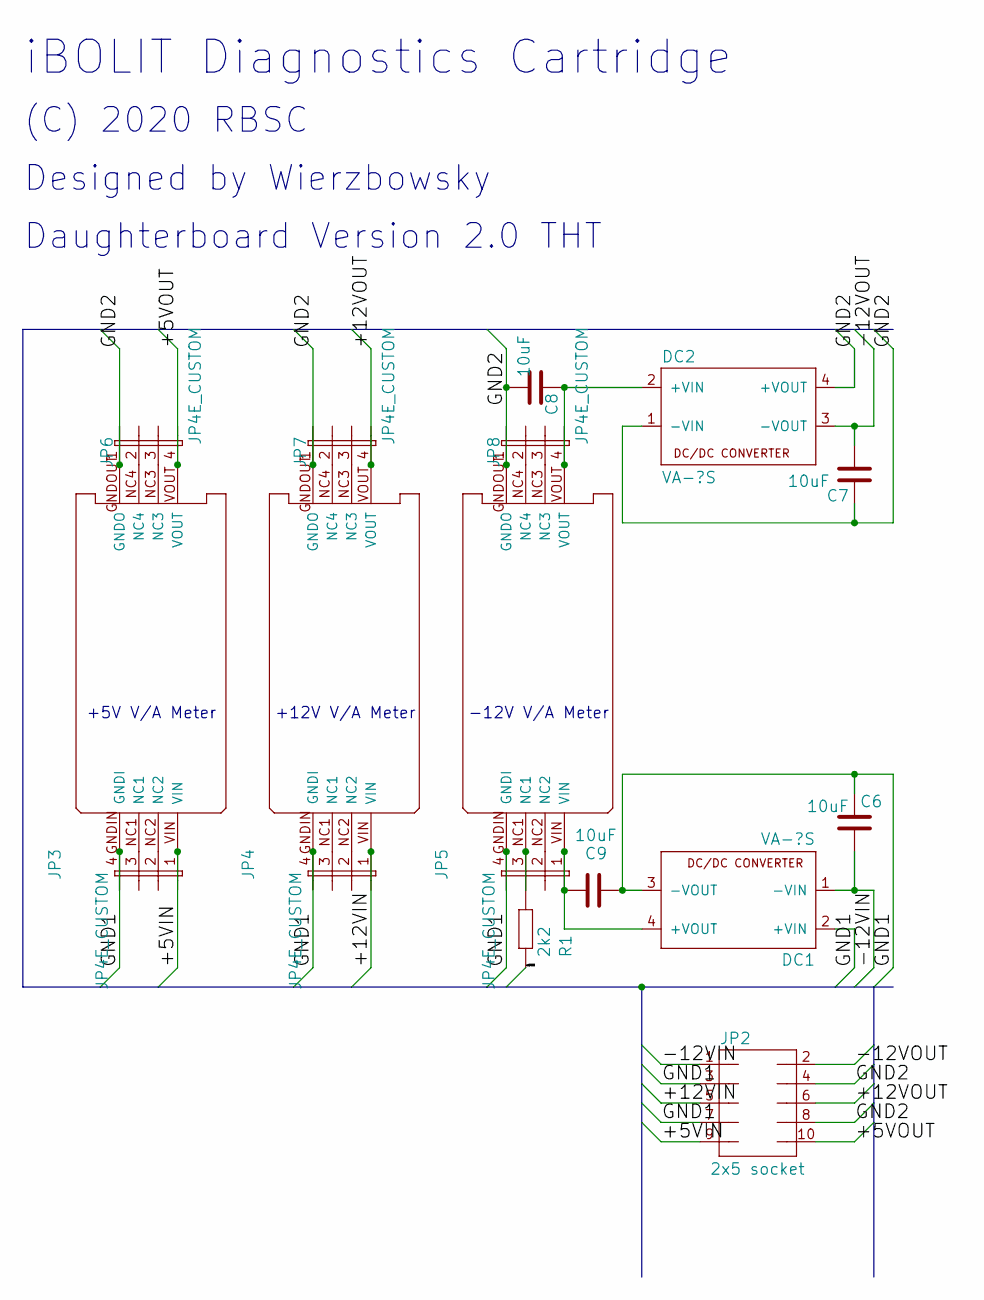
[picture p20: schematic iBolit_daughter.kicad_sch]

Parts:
C6, C7, C8, C9: 10uF; C_Disc_D4.7mm_W2.5mm_P5.00mm
DC1, DC2: VA-?S; 4SIL
JP2: 2x5 socket; JP5Q_CUSTOM
JP3, JP4, JP5, JP6, JP7, JP8: JP4E_CUSTOM; JP4_CUSTOM
R1: 2k2; R_Axial_DIN0207_L6.3mm_D2.5mm_P7.62mm_Horizontal
X1, X2, X3: VA-METER; VA_METER

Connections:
/+5VIN: JP2.9, JP3.1, R1.1, X1.VIN
/+5VOUT: JP2.10, JP6.4, X1.VOUT
/+12VIN: JP2.5, JP4.1, X2.VIN
/+12VOUT: JP2.6, JP7.4, X2.VOUT
/-12VIN: C6.2, DC1.1 (-VIN), JP2.1
/-12VOUT: C7.2, DC2.3 (-VOUT), JP2.2
/GND1: C6.1, C9.2, DC1.2 (+VIN), DC1.3 (-VOUT), JP2.3, JP2.7, JP3.4, JP4.4, JP5.4, X1.GNDIN (GNDI), X2.GNDIN (GNDI), X3.GNDIN (GNDI)
/GND2: C7.1, C8.2, DC2.1 (-VIN), DC2.4 (+VOUT), JP2.4, JP2.8, JP6.1, JP7.1, JP8.1, X1.GNDOUT (GNDO), X2.GNDOUT (GNDO), X3.GNDOUT (GNDO)
unnamed: C8.1, DC2.2 (+VIN), JP8.4, X3.VOUT
unnamed: JP3.2, X1.NC2
unnamed: JP3.3, X1.NC1
unnamed: JP4.2, X2.NC2
unnamed: JP4.3, X2.NC1
unnamed: C9.1, DC1.4 (+VOUT), JP5.1, X3.VIN
unnamed: JP5.2, X3.NC2
unnamed: JP5.3, R1.2, X3.NC1
unnamed: JP6.2, X1.NC4
unnamed: JP6.3, X1.NC3
unnamed: JP7.2, X2.NC4
unnamed: JP7.3, X2.NC3
unnamed: JP8.2, X3.NC4
unnamed: JP8.3, X3.NC3

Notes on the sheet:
iBOLIT Diagnostics Cartridge
Daughterboard Version 2.0 THT
+12V V/A Meter
+5V V/A Meter
(C) 2020 RBSC
Designed by Wierzbowsky
-12V V/A Meter

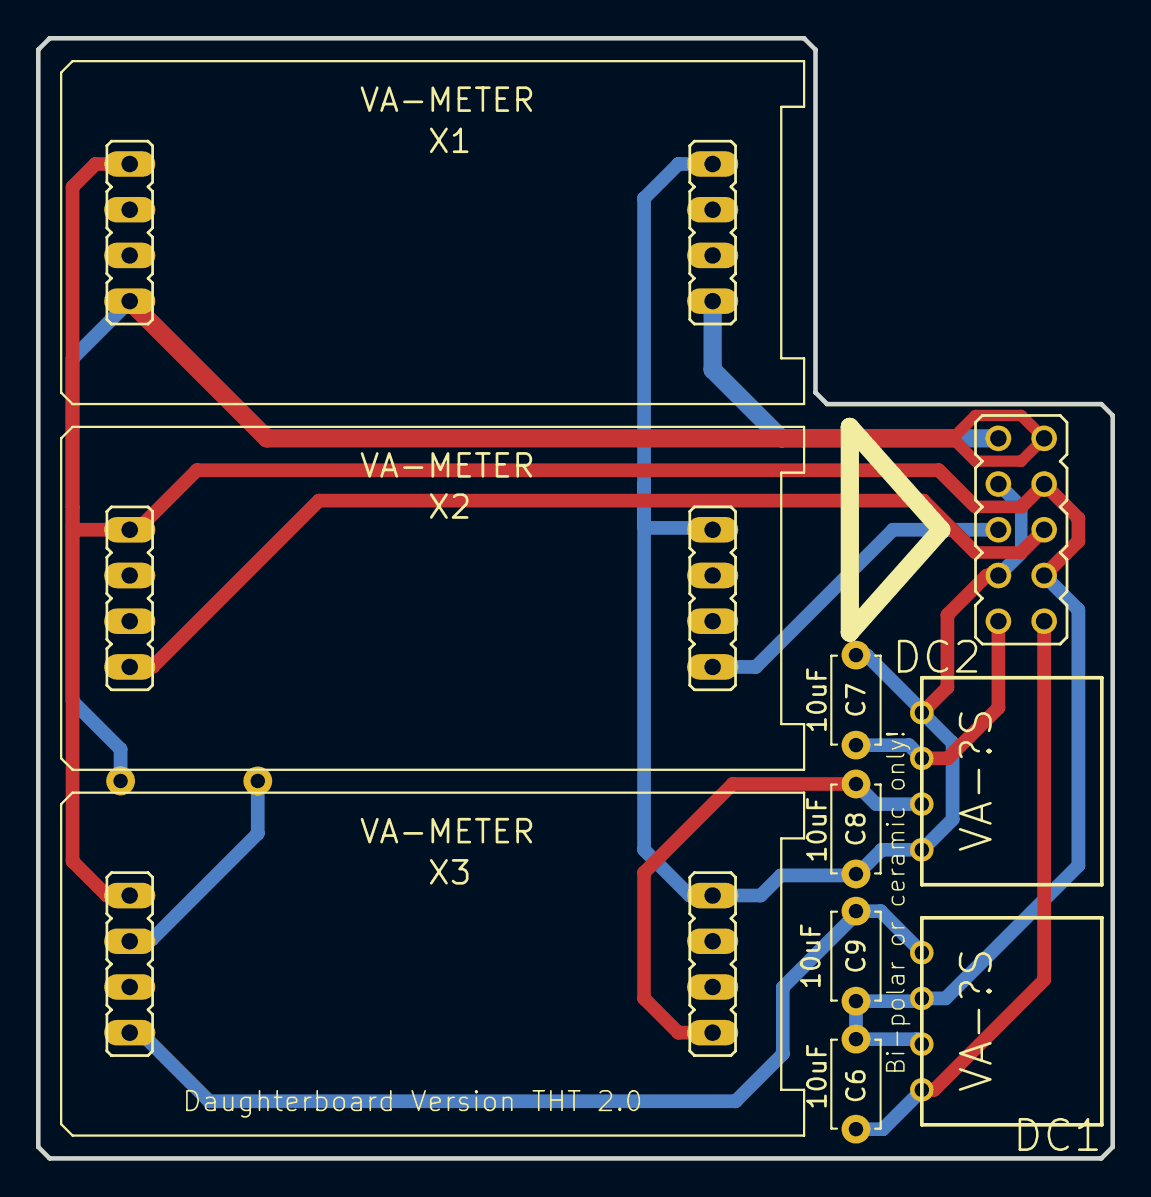
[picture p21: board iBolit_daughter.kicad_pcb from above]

Board: 2 copper layers, 59.7 x 62.2 mm, 17 parts (1 on the bottom side), 22 nets.
